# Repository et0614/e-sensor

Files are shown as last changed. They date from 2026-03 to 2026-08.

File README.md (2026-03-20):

# E-Sensor Project

This project provides a complete solution for a MIDI-based sensor device, including hardware design files, microcontroller firmware, and a Python client library.

## Directory Structure

The repository is organized as follows:

```text
.
├── firmware/                # Microcontroller Firmware (MPLAB X IDE)
│   ├── E_Sensor_Main.X/     # Main controller (USB-MIDI & System Logic)
│   └── E_Sensor_Velocity.X/ # Sub-controller (Air velocity sensor processing)
├── hardware/                # Hardware Design Materials
│   ├── pcb/                 # PCB layout and schematics
│   ├── datasheets/          # Technical specifications for key components
│   └── BOM.xlsx             # Bill of Materials
├── software/                # PC-side Applications & Libraries
│   ├── e_sensor.py          # Python client library for E-Sensor
│   └── requirements.txt     # Python dependency list
└── .gitignore               # Git ignore rules for MPLAB X and Python
```

---

## Directory Details

### 1. Firmware (`/firmware`)
Contains MPLAB X IDE projects for the onboard microcontrollers.

* **E_Sensor_Main.X**: 
    * Handles USB-MIDI communication using the TinyUSB stack.
    * Manages system-level logic and MIDI SysEx protocol.
    * Configured via MCC (MPLAB Code Configurator).
* **E_Sensor_Velocity.X**: 
    * Dedicated firmware for the air velocity sensor subunit.
    * Focuses on high-speed signal processing and data filtering.

### 2. Hardware (`/hardware`)
Includes all physical design assets.

* **pcb/**: Original CAD files for the board. A `Schematic.pdf` is provided for quick reference without needing specialized CAD software.
* **datasheets/**: A collection of PDFs for the ICs and sensors used in this design, ensuring all technical references are available offline.

### 3. Software (`/software`)
Tools for interfacing with the device from a computer.

* **e_sensor.py**: 
    * A lightweight Python class that wraps the MIDI SysEx protocol.
    * Supports real-time data polling, device ID retrieval, and coefficient calibration.
* **requirements.txt**: List of necessary Python packages (e.g., `mido`, `python-rtmidi`).

---

## Getting Started

### Firmware Development
* **IDE**: MPLAB X IDE
* **Compiler**: Microchip XC8
* **Plugin**: MCC (MPLAB Code Configurator)

### Python Environment
Install dependencies using pip:
```bash
pip install -r software/requirements.txt
```

---

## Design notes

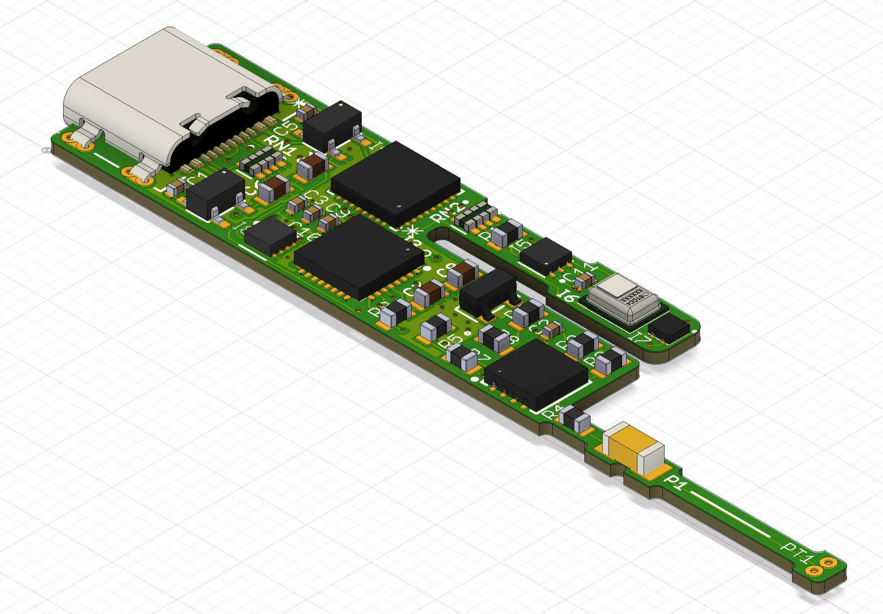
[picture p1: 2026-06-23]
hardware/pcb/3d_view.png

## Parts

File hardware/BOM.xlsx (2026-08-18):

No. | Designator | Qty | Manufacturer | Manufacturer Part Number | Spec | RoHS | Link
1 | C1, C2, C3, C5, C9, C10, C11 | 7 | Samsung Electro-Mechanics | CL05B104KO5NNNC | 0.1 uF | x | https://www.lcsc.com/product-detail/C1525.html
2 | C4, C6, C7 | 3 | Samsung Electro-Mechanics | CL10A105KB8NNNC | 1 uF | x | https://jlcpcb.com/partdetail/16531-CL10A105KB8NNNC/C15849
3 | C8 | 1 | Murata | GRM188R60J476ME15D | 47 uF | x | https://www.digikey.jp/ja/products/detail/murata-electronics/GRM188R60J476ME15D/5877410
4 | I1 | 1 | Toshiba | TCR2EF33,LM | 3.3 V | x | https://www.digikey.jp/ja/products/detail/toshiba-semiconductor-and-storage/TCR2EF33-LM-CT/4503183
5 | I2 | 1 | Toshiba | TCR3UF20A,LM(CT | 2.0 V | x | https://www.lcsc.com/product-detail/C7067134.html
6 | I3 | 1 | ATmel | AVR128DB32T-E/RXB |  | x | https://www.digikey.jp/ja/products/detail/microchip-technology/AVR128DB32T-E-RXB/12807276
7 | I4 | 1 | ATmel | AVR64DU32-I/RXB |  | x | https://www.digikey.jp/ja/products/detail/microchip-technology/AVR64DU32-I-RXB/22611635
8 | I5 | 1 | Texas Instruments | OPT3001 |  | x | https://www.digikey.jp/ja/products/detail/texas-instruments/OPT3001DNPR/5039362
9 | I6 | 1 | Sensirion | SHT40-AD1B |  | x | https://www.digikey.jp/ja/products/detail/sensirion-ag/SHT40-AD1B-R3/14322709
10 | I7 | 1 | Sensirion | STCC4-D-R3 | CO2 | x | https://www.digikey.jp/ja/products/detail/sensirion-ag/STCC4-D-R3/26769073
11 | I8 | 1 | Texas Instruments | TPS22965DSGR |  | x | https://www.lcsc.com/product-detail/C122837.html
12 | J1 | 1 | Korean Hroparts Elec | TYPE-C-31-M-14 | Type C | x | https://www.lcsc.com/product-detail/C223907.html
13 | O1 | 1 | Microchip Technology | MCP6V02-E/MD |  | x | https://www.digikey.jp/ja/products/detail/microchip-technology/MCP6V02-E-MD/1635826
14 | P1 | 1 | VISHAY | TFPT1206L1002FV |  | x | https://www.digikey.jp/ja/products/detail/vishay-dale/TFPT1206L1002FV/1427100
15 | Q1 | 1 | JSCJ | JSCJ MMBT3904(RANGE:100-300) |  | x | https://www.lcsc.com/product-detail/C20526.html
16 | R2 | 1 | TE Connectivity Passive Product | CPF0603B2R21E1 | 2.21 Ω, 0.1%, 25ppm/C | x | https://www.digikey.jp/ja/products/detail/te-connectivity-passive-product/CPF0603B2R21E1/14007137
17 | R3 | 1 | TE Connectivity Passive Product | RQ73C1J232RBTD | 232 Ω, 0.1%, 10ppm/C | x | https://www.digikey.jp/ja/products/detail/te-connectivity-passive-product/RQ73C1J232RBTD/9480531
18 | R4 | 1 | TE Connectivity Passive Product | RQ73C1J2K74BTD | 2.74 kΩ, 0.1%, 10ppm/C | x | https://www.digikey.jp/ja/products/detail/te-connectivity-passive-product/RQ73C1J2K74BTD/9480545
19 | R5, R6 | 2 | TE Connectivity Passive Product | RQ73C1J15KBTD | 15 kΩ, 0.1%, 10ppm/C | x | https://www.digikey.jp/ja/products/detail/te-connectivity-passive-product/RQ73C1J15KBTD/9480247
20 | R7, R8 | 2 | TE Connectivity Passive Product | RQ73C1J13KBTD | 13 kΩ, 0.1%, 10ppm/C | x | https://www.digikey.jp/ja/products/detail/te-connectivity-passive-product/RQ73C1J13KBTD/9480097
21 | R9 | 1 | UNI-ROYAL | 0603WAF4701T5E | 4.7 kΩ | x | https://www.lcsc.com/product-detail/C23162.html
22 | RN1, RN2 | 2 | Panasonic | EXB-28V103JX | 10 kΩ x 4 | x | https://www.digikey.jp/ja/products/detail/panasonic-electronic-components/EXB-28V103JX/256299
23 | PT1 | 1 | Yageo Nexensos | 32208551 |  | x | https://www.digikey.jp/ja/products/detail/yageo-nexensos/32208551/6677784

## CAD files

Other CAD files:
hardware/pcb/e_sensor.f3z

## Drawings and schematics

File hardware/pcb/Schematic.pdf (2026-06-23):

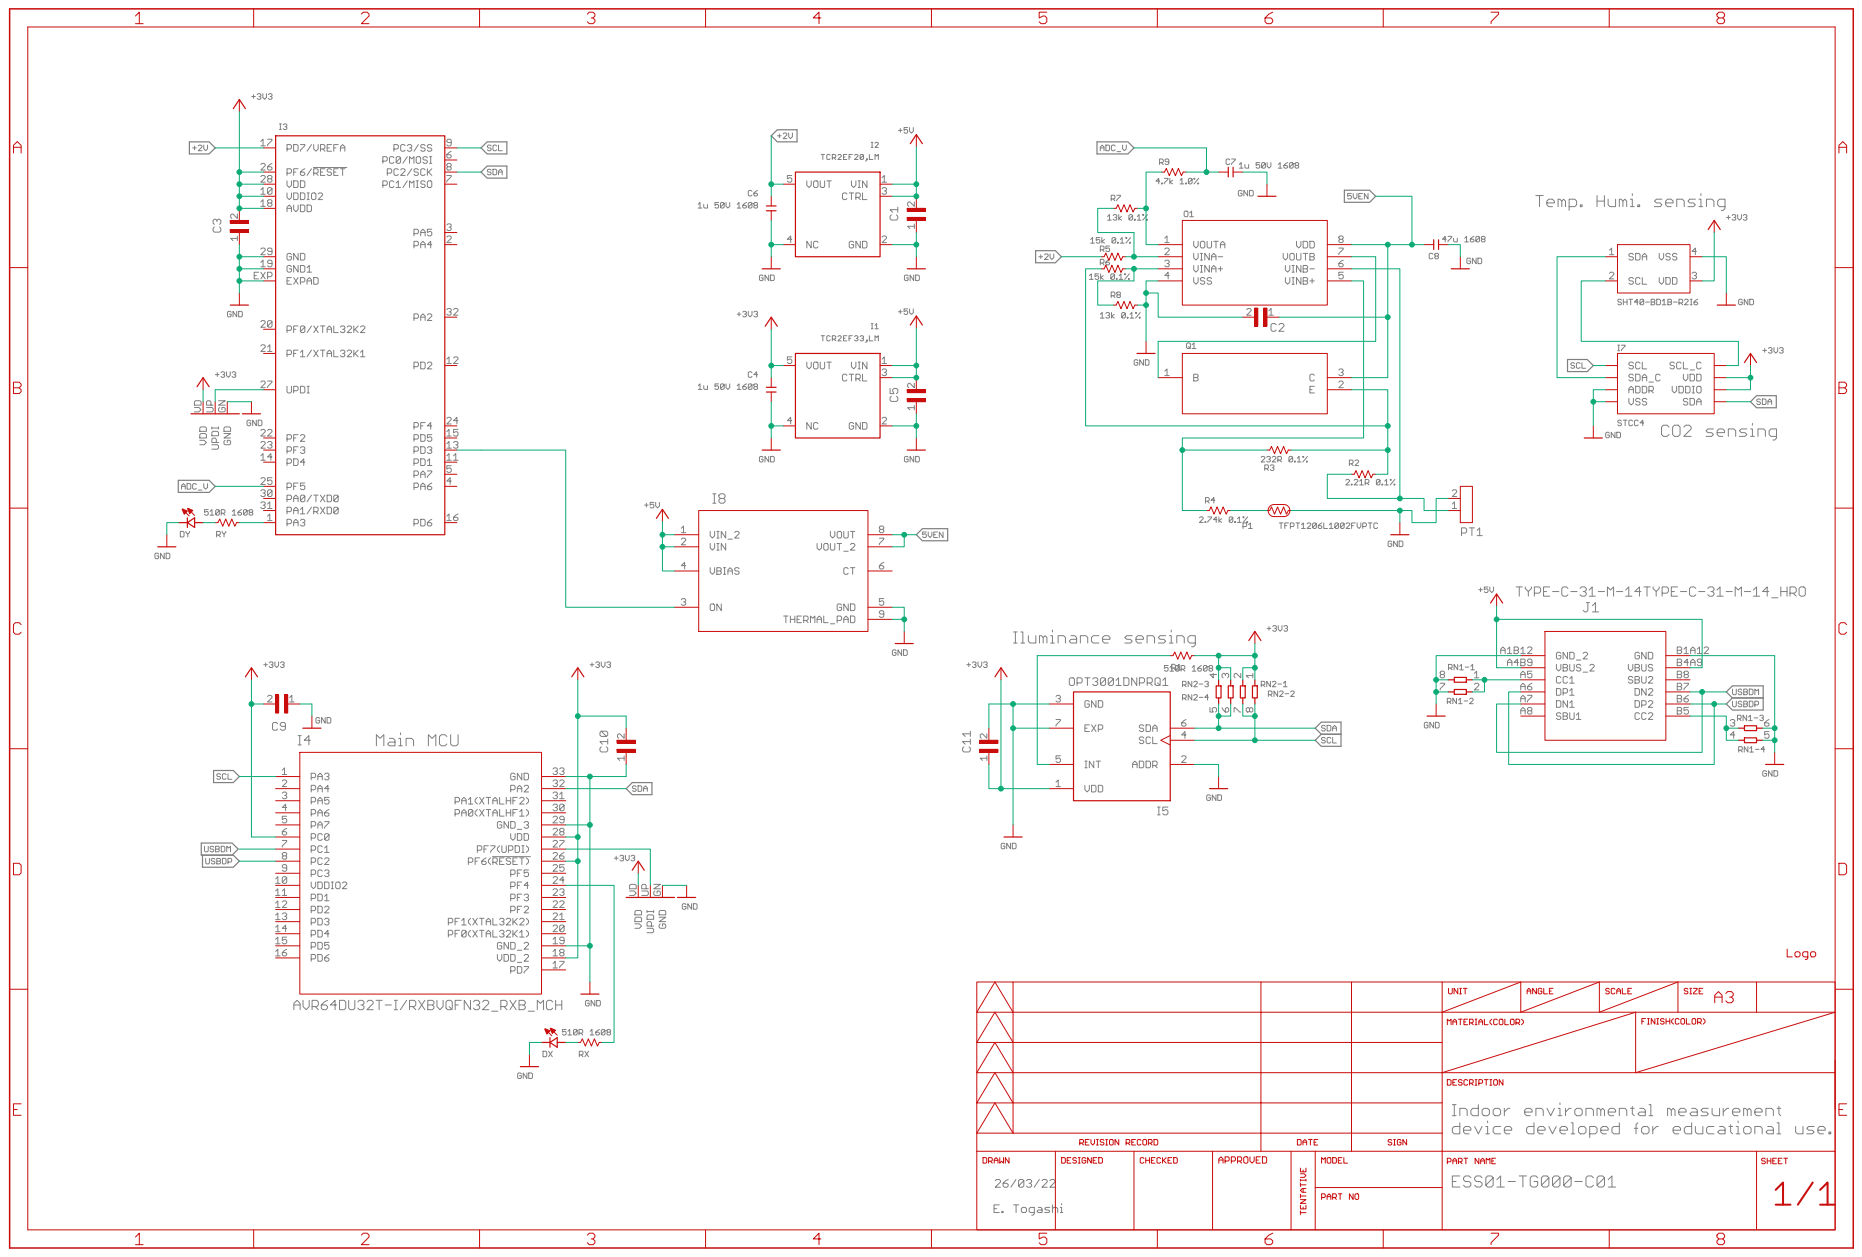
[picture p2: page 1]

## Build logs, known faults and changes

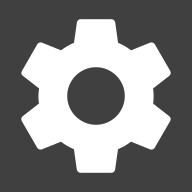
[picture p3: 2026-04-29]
software/maui/E-Sensor/Resources/Images/maintenance.png

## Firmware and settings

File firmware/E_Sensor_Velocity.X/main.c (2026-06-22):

 /*
 * AVR128DB32による風速計プログラム。
 * ブリッジ回路を応用した定温熱線式風速計の電圧を読み取り、風速に換算してI2C通信でデータを送受信する
*/

// <editor-fold defaultstate="collapsed" desc="include">

#include "mcc_generated_files/system/system.h"
#include "mcc_generated_files/adc/adc0.h"
#include "mcc_generated_files/system/pins.h"
#include "mcc_generated_files/timer/rtc.h"

#include "utility.h"
#include "i2c_slave.h"
#include "i2c_shared_data.h"
#include "smooth_filter.h"
#include "eeprom_manager.h"

#include <util/atomic.h>
#include <string.h>
#include <math.h>
#include <avr/sleep.h>
#include <avr/wdt.h>

// </editor-fold>

// <editor-fold defaultstate="collapsed" desc="定数宣言">

#define VERSION_NUMBER  (2)

#define HEATING_MSEC    (5000)  //立ち上げのための白金抵抗予熱時間[msec]

#define INTERRUPT_MSEC  (20)    //タイマの割り込み時間間隔[msec]

#define TEMP_UPDATE_MSEC (1000) //温度の更新時間間隔[msec]

#define RESET_TIME (3000)       // Resetをかけるまでの時間 [msec]

// </editor-fold>

// <editor-fold defaultstate="collapsed" desc="変数定義">

//定期更新カウンタ
volatile uint8_t tick_count = 0;

volatile uint16_t reset_timer = RESET_TIME;

//立ち上げのための白金抵抗予熱時間[msec]
uint16_t heating_timer = HEATING_MSEC;

uint16_t temp_timer = TEMP_UPDATE_MSEC;

//風速電圧平滑化フィルタ
SmoothFilter velFilter;

// </editor-fold>

// <editor-fold defaultstate="collapsed" desc="温度測定">

// 温度測定
void updateTemperature()
{
    // チャンネルを温度センサに切り替える
    ADC0_ChannelSelect(ADC0_CHANNEL_TEMPSENSE);
    
    // サンプリング時間（風速計とは異なり高インピーダンスのため）
    ADC0.SAMPCTRL = 100;
    
    // 初期遅延(INITDLY)を設定：最大の 256 CLK_ADC を待機
    ADC0.CTRLD &= 0x1F;
    
    ADC0_ConversionStart(); // 変換開始
    while(!ADC0_IsConversionDone()); // 完了待ち (BUSYフラグが落ちるのを待つ)
    adc_accumulate_t acc_val = ADC0_AccumulatedResultGet(); // 結果を取得

    //符号反転を防ぎながらキャスト
    uint32_t safe_val = (uint32_t)acc_val;
    uint32_t voltage = safe_val * 2000UL / (4096UL * 16UL); // (12bit(4096), 128 回平均, 19bitになりAVRの仕様で3bit切り捨てられるので8で割られていることに等しい)
    
    // 2.048V基準時のADCカウント数に換算
    // 12bit ADC(4096)において 2048mV = 4096カウント なので 1mV = 2カウント
    int32_t adc_equiv = (int32_t)voltage * 2;

    // 5. 特性式を適用 (公式: T[K] = (ADC - Offset) * Gain / 4096)
    int32_t gain = (int32_t)SIGROW.TEMPSENSE0;   // 16bit Gain
    int32_t offset = (int32_t)SIGROW.TEMPSENSE1; // 16bit Offset
    
    // 0.1度単位でのケルビン温度を計算
    int32_t temp_k_x100 = ((offset - adc_equiv) * gain * 100) / 4096;
    
    uint8_t vol[2];
    vol[0] = (uint8_t)(temp_k_x100 >> 8);
    vol[1] = (uint8_t)(temp_k_x100 & 0xFF);
    uint8_t volCrc = calc_crc8(vol, sizeof(vol));
    
    ATOMIC_BLOCK(ATOMIC_RESTORESTATE) {
        SharedMemory.reg.mcu_temp_high = vol[0];
        SharedMemory.reg.mcu_temp_low  = vol[1];
        SharedMemory.reg.mcu_temp_crc = volCrc;
    }
}

// </editor-fold>

// <editor-fold defaultstate="collapsed" desc="風速測定関連">

// 風速を表す電圧のAD変換処理
uint32_t adcVelocityVoltage()
{
    if(!SharedMemory.reg.enable) return 0;
    
    //チャンネルを風速計に切り替える
    ADC0_ChannelSelect(ADC0_CHANNEL_AIN21);
    
    // サンプリング時間（小さくて良い）
    ADC0.SAMPCTRL = 0;
    
    // 初期遅延(INITDLY)を設定：0
    ADC0.CTRLD |= ADC_INITDLY_DLY0_gc;
    
    ADC0_ConversionStart(); // 変換開始
    while(!ADC0_IsConversionDone()); // 完了待ち (BUSYフラグが落ちるのを待つ)
    adc_accumulate_t acc_val = ADC0_AccumulatedResultGet(); // 結果を取得
    
    //符号反転を防ぎながらキャスト
    uint32_t safe_val = (uint32_t)acc_val;
    return  safe_val * 2000UL / (4096UL * 16UL); // (12bit(4096), 128 回平均, 19bitになりAVRの仕様で3bit切り捨てられるので8で割られていることに等しい)
}

// 風速を表す電圧を平滑化して更新
void updateVelocityVoltage()
{
    uint32_t voltage = adcVelocityVoltage();
    SF_Apply(&velFilter, voltage);

    uint8_t vol[2];
    vol[0] = (uint8_t) (velFilter.out_y >> 8);
    vol[1] = (uint8_t) (velFilter.out_y & 0xFF);
    uint8_t volCrc = calc_crc8(vol, sizeof(vol));

    //安全に書き込み
    ATOMIC_BLOCK(ATOMIC_RESTORESTATE) {
        // ビッグエンディアンで保存(下位と上位を入れ替え)
        SharedMemory.reg.voltage_high = vol[0]; // Voltage High Byte
        SharedMemory.reg.voltage_low = vol[1]; // Voltage Low Byte
        SharedMemory.reg.voltage_crc = volCrc; // Voltage CRC
    }
}

// 風速を更新
void updateVelocity()
{
    //係数取得
    float coA[5];
    ATOMIC_BLOCK(ATOMIC_RESTORESTATE) {
        memcpy(coA, (void*)SharedMemory.reg.coefficientA, sizeof(coA));
    }
    for(int i=0; i<5; i++) swap_float(&coA[i]);
    float coB[5];
    ATOMIC_BLOCK(ATOMIC_RESTORESTATE) {
        memcpy(coB, (void*)SharedMemory.reg.coefficientB, sizeof(coB));
    }
    for(int i=0; i<5; i++) swap_float(&coB[i]);
    
    // --- 3レンジ用パラメータの割り当て ---
    float vol0    = coA[0]; // 無風電圧 [V]    
    // Range 1 (Low)
    float m1      = coA[1];
    float lnC1    = coA[2];    
    // Range 2 (Mid)
    float m2      = coA[3];
    float lnC2    = coA[4];    
    // Range 3 (High)
    float m3      = coB[0];
    float lnC3    = coB[1];    
    // 切替ポイント
    float v_split1 = coB[2]; // 1つ目の切替点
    float v_split2 = coB[3]; // 2つ目の切替点

    uint16_t mVolt = (SharedMemory.reg.voltage_high << 8) + (SharedMemory.reg.voltage_low);
    float evv = (0.001 * mVolt) * (0.001 * mVolt) - vol0 * vol0;
    float vel_f;
    //無風電圧以下は確定的に0m/s
    if(evv <= 0) vel_f = 0;
    else 
    {
        float lnev = log(evv);
        // まず Range 1 で計算
        vel_f = exp(lnev * m1 + lnC1);
        // 切り替え点1を超えていたらRange 2で計算
        if(v_split1 <= vel_f) 
        {
            vel_f = exp(lnev * m2 + lnC2);            
            // さらに切替点2を超えていたら Range 3 で再計算
            if(v_split2 <= vel_f) vel_f = exp(lnev * m3 + lnC3);
        }
    }
    
    // mm/sに変換して16ビット整数化
    uint16_t vel_ui = (uint16_t) (vel_f * 1000);
    uint8_t vel[2];
    vel[0] = (uint8_t)(vel_ui >> 8);
    vel[1] = (uint8_t)(vel_ui & 0xFF);
    
    //CRC計算
    uint8_t velCrc = calc_crc8(vel, sizeof(vel));
    
    //安全に書き込み
    ATOMIC_BLOCK(ATOMIC_RESTORESTATE) {
        SharedMemory.reg.velocity_high = vel[0]; // Velocity High Byte
        SharedMemory.reg.velocity_low = vel[1]; // Velocity Low Byte
        SharedMemory.reg.velocity_crc = velCrc; // Velocity CRC
    }
}

// </editor-fold>

// <editor-fold defaultstate="collapsed" desc="main">

// 20msecタイマ用コールバック関数
void msecHandler(void) 
{
    if (tick_count < 255) tick_count++;
}

bool ledDbg = true;

int main(void)
{
    SYSTEM_Initialize();
        
    // EEPROM読み込み
    EM_loadEEPROM();
    
    // I2Cアドレスを反映
    TWI0.SADDR = SharedMemory.reg.i2c_address << 1;
    
    // デフォルトの設定
    SharedMemory.reg.version = VERSION_NUMBER;
    SharedMemory.reg.enable = 0; // 起動時は風速計OFF（5V遮断）。Main からの起動指令で開始する
    SharedMemory.reg.updated = 0;
    memcpy((void*)SharedMemory.reg.id, (const void*)&SIGROW.SERNUM0, 16); // AVR製造IDをコピー
    SharedMemory.reg.id_crc = calc_crc8((uint8_t*)SharedMemory.reg.id, 16);
    uint32_t hash = fnv1a_32((void*)SharedMemory.reg.id, sizeof(SharedMemory.reg.id));
    SharedMemory.reg.id_hash[0] = (uint8_t)(hash >> 24);
    SharedMemory.reg.id_hash[1] = (uint8_t)(hash >> 16);
    SharedMemory.reg.id_hash[2] = (uint8_t)(hash >> 8);
    SharedMemory.reg.id_hash[3] = (uint8_t)(hash & 0xFF);
    SharedMemory.reg.id_hash_crc = calc_crc8((uint8_t*)SharedMemory.reg.id_hash, 4);
    
    // 風速回路の5V電源制御（SLP = PD3 → TPS22965 ON ピン, Active High）。
    // High で5Vを供給して風速回路ON、Low で5Vを遮断してOFF（自己発熱を停止）。
    // 起動直後は enable=1 のため5Vを供給して白金抵抗の予熱を開始する。
    if (SharedMemory.reg.enable) SLP_SetHigh();
    else SLP_SetLow();

    // イベントハンドラ登録
    RTC_SetOVFIsrCallback(msecHandler);
    
    // I2C通信初期化
    I2C_Slave_Init();
    
    // 風速電圧平滑化フィルタの初期化
    SF_Init(&velFilter, SharedMemory.reg.filter_n, 0); //平滑化の目安：2^6*INTERRUPT_MSEC(1.28 sec)
        
    // スリープモード設定
    set_sleep_mode(SLEEP_MODE_IDLE);
    
    // 割り込み開始
    sei();
    
    uint8_t prev_enabled = SharedMemory.reg.enable;
    while(1)
    {
        // WDT (FUSE で 4.1s) のキック。EEPROM 書き込み・I2C 通信・浮動小数点計算など
        // 比較的長い処理を含むがいずれも秒オーダ未満で完了するため、ループ先頭の
        // 1 か所で十分。SLEEP_MODE_IDLE では WDT も計時継続するが、I2C/RTC 割込で
        // 短時間で復帰してここを通る。
        wdt_reset();

        // マスタからの設定変 更リクエストを確認
        if (I2C_Config_Update_Requested)
        {
            I2C_Config_Update_Requested = false;

            // Main からのスリープ/起動指令（enable レジスタ）に応じて
            // 風速回路の5V電源（PD3 → TPS22965 ON, Active High）を切り替える
            if (prev_enabled != SharedMemory.reg.enable)
            {
                if(SharedMemory.reg.enable == 1)
                {
                    // 5V回路起動（PD3=High → TPS22965 ON）
                    SLP_SetHigh();

                    // 再給電直後は白金抵抗が冷えているため予熱時間をリセット
                    heating_timer = HEATING_MSEC;
                }
                // 5V回路停止（PD3=Low → TPS22965 OFF、自己発熱を停止）
                else SLP_SetLow();
                
                // 状態を保存
                prev_enabled = SharedMemory.reg.enable;
            }            
            
            // 現在の出力値を初期値として、新しい n 数でフィルタを再初期化
            SF_Init(&velFilter, SharedMemory.reg.filter_n, velFilter.out_y);
            
            //EEPROMを更新
            EM_updateEEPROM();
        }
        
        //係数変更リクエストを確認
        if(I2C_Coefficient_Update_Requested)
        {
            I2C_Coefficient_Update_Requested = false;
            
            //EEPROMを更新
            EM_updateEEPROM();
        }
        
        // 定期更新処理
        if(tick_count)
        {
            ATOMIC_BLOCK(ATOMIC_RESTORESTATE) { tick_count--; }
            // I2C有効時間を更新
            if(0 < I2C_KeepAlive_Ticks)
            {
                ATOMIC_BLOCK(ATOMIC_RESTORESTATE) { 
                    I2C_KeepAlive_Ticks = (I2C_KeepAlive_Ticks < INTERRUPT_MSEC) ? 0 : (I2C_KeepAlive_Ticks - INTERRUPT_MSEC);
                }
            }
                        
            //リセット処理
            /*if(RST_SW_GetValue() == 0)
            {
                reset_timer = reset_timer < INTERRUPT_MSEC ? 0 : reset_timer - INTERRUPT_MSEC;
                if(reset_timer == 0)
                {
                    // EEPROMの初期化処理
                    EM_resetEEPROM();
                    reset_timer = RESET_TIME;
                }
            }
            else reset_timer = RESET_TIME;*/
            
            //残予熱時間を更新
            heating_timer = (heating_timer < INTERRUPT_MSEC) ? 0 : (heating_timer - INTERRUPT_MSEC);
            
            // ステータスレジスタの更新
            ATOMIC_BLOCK(ATOMIC_RESTORESTATE) {
                if (heating_timer > 0) SharedMemory.reg.status |= STATUS_HEATING_MASK; // 予熱中
                else SharedMemory.reg.status &= ~STATUS_HEATING_MASK; // 予熱完了
            }
                        
            //計測準備が整っていれば
            if (SharedMemory.reg.enable == 1 && heating_timer == 0) 
            {
                // 風速電圧[mV]を更新
                updateVelocityVoltage();
                
                // 風速[mm/s]を更新
                updateVelocity();
                
                // 計測フラグ更新
                SharedMemory.reg.updated = 1;
            }
            
            // 温度更新
            temp_timer = (temp_timer < INTERRUPT_MSEC) ? 0 : (temp_timer - INTERRUPT_MSEC);
            if(temp_timer == 0)
            {
                updateTemperature();
                temp_timer = TEMP_UPDATE_MSEC;
            }
            
            //DEBUG*****
            if(SharedMemory.reg.enable == 1) R_LED_SetHigh();
            else R_LED_SetLow();
            //DEBUG*****
        }
        
        // スリープモードは常に IDLE とする。
        // 停止中(enable=0)に PWR_DOWN へ入れると RTC が停止して msecHandler が来ず、
        // メインループが回らないため wdt_reset() を呼べない。WDT(FUSE 4.1s)が有効だと
        // 約4秒でWDTリセットがかかり、再起動時に enable=1(既定)へ戻って 5V(PD3) が
        // 復活してしまう（OFF にしても数秒で給電が戻る不具合）。IDLE なら RTC 割込で
        // 20ms 毎に起床して WDT をキックし続けるため、enable=0(PD3 Low, 5V OFF) を
        // 保持できる。発熱源である 5V 回路は PD3 で遮断済みのため目的は達成される。
        // ※さらに深い省電力(PWR_DOWN)が必要なら FUSE で WDT を無効化する必要がある。
        set_sleep_mode(SLEEP_MODE_IDLE);
        sleep_mode();
    }    
}

// </editor-fold>

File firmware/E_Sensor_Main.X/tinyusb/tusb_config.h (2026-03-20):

/*
 * The MIT License (MIT)
 *
 * Copyright (c) 2019 Ha Thach (tinyusb.org)
 *
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
 */

#ifndef _TUSB_CONFIG_H_
#define _TUSB_CONFIG_H_

#ifdef __cplusplus
 extern "C" {
#endif

//--------------------------------------------------------------------+
// Board Specific Configuration
//--------------------------------------------------------------------+

// RHPort number used for device can be defined by board.mk, default to port 0
#ifndef BOARD_TUD_RHPORT
#define BOARD_TUD_RHPORT      0
#endif

// RHPort max operational speed can defined by board.mk
#ifndef BOARD_TUD_MAX_SPEED
#define BOARD_TUD_MAX_SPEED   OPT_MODE_DEFAULT_SPEED
#endif

//--------------------------------------------------------------------
// Common Configuration
//--------------------------------------------------------------------

// defined by compiler flags for flexibility
#ifndef CFG_TUSB_MCU
//#error CFG_TUSB_MCU must be defined
#define CFG_TUSB_MCU OPT_MCU_AVRDU
#endif

#ifndef CFG_TUSB_OS
#define CFG_TUSB_OS           OPT_OS_NONE
#endif

#ifndef CFG_TUSB_DEBUG
#define CFG_TUSB_DEBUG        0
#endif

// Enable Device stack
#define CFG_TUD_ENABLED       1

// Default is max speed that hardware controller could support with on-chip PHY
#define CFG_TUD_MAX_SPEED     BOARD_TUD_MAX_SPEED

/* USB DMA on some MCUs can only access a specific SRAM region with restriction on alignment.
 * Tinyusb use follows macros to declare transferring memory so that they can be put
 * into those specific section.
 * e.g
 * - CFG_TUSB_MEM SECTION : __attribute__ (( section(".usb_ram") ))
 * - CFG_TUSB_MEM_ALIGN   : __attribute__ ((aligned(4)))
 */
#ifndef CFG_TUSB_MEM_SECTION
#define CFG_TUSB_MEM_SECTION
#endif

#ifndef CFG_TUSB_MEM_ALIGN
#define CFG_TUSB_MEM_ALIGN    __attribute__ ((aligned(4)))
#endif

//--------------------------------------------------------------------
// DEVICE CONFIGURATION
//--------------------------------------------------------------------

#ifndef CFG_TUD_ENDPOINT0_SIZE
#define CFG_TUD_ENDPOINT0_SIZE   64
#endif

//------------- CLASS -------------//
#define CFG_TUD_CDC              0
#define CFG_TUD_MSC              0
#define CFG_TUD_HID              0
#define CFG_TUD_MIDI             1 //MIDI有効化
#define CFG_TUD_VENDOR           0

#define CFG_TUD_CDC_NOTIFY        1 // Enable use of notification endpoint

// CDC FIFO size of TX and RX
#define CFG_TUD_CDC_RX_BUFSIZE   (TUD_OPT_HIGH_SPEED ? 512 : 64)
#define CFG_TUD_CDC_TX_BUFSIZE   (TUD_OPT_HIGH_SPEED ? 512 : 64)

// CDC Endpoint transfer buffer size, more is faster
#define CFG_TUD_CDC_EP_BUFSIZE   (TUD_OPT_HIGH_SPEED ? 512 : 64)

// MSC Buffer size of Device Mass storage
#define CFG_TUD_MSC_EP_BUFSIZE   512
     
//------------- MIDI CLASS DRIVER CONFIGURATION -------------//
// MIDIパケットのバッファサイズを設定します
// AVR64DU32（Full Speed）の場合、通常は64バイトが標準的
#define CFG_TUD_MIDI_RX_BUFSIZE  64  // 受信バッファサイズ
#define CFG_TUD_MIDI_TX_BUFSIZE  64  // 送信バッファサイズ

// USBポート0を「デバイスモード」かつ「フルスピード」で動作させる定義
#define CFG_TUSB_RHPORT0_MODE     (OPT_MODE_DEVICE | OPT_MODE_FULL_SPEED)

#ifndef CFG_TUSB_MCU
#define CFG_TUSB_MCU OPT_MCU_AVRDU
#endif
     
#ifdef __cplusplus
 }
#endif

#endif /* _TUSB_CONFIG_H_ */

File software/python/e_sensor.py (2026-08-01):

import mido
import struct
import time
import math
from dataclasses import dataclass
from typing import Optional, List, Callable, Tuple
import datetime

@dataclass
class SensorData:
    """パース済みのセンサーデータ構造体"""
    timestamp: float
    illuminance: float  # lx
    temperature: float   # C
    humidity: float      # %
    velocity: float     # m/s (内部ではmm/sで管理されているものを変換)
    voltage: float      # V
    co2: int           # ppm
    ill_valid: bool    # Bit 0 (照度)
    env_valid: bool    # Bit 1 (温湿度・CO2)
    anemo_valid: bool  # Bit 2 (風速・電圧)
    # 風速計自己発熱の温度補正(カルマンフィルタ)が有効な場合に、補正後の
    # 空気温度推定値[℃]が入る。補正無効時や温湿度無効時は None。
    # 生の temperature は補正に関わらずそのまま保持される。
    corrected_temperature: Optional[float] = None
    # 温度補正に伴って換算し直した相対湿度[%]。補正無効時や温湿度無効時は None。
    # 生の humidity はそのまま保持される。
    corrected_humidity: Optional[float] = None


class ThermalParams:
    """風速計の自己発熱による温度センサ熱影響モデルの定数。

    資料「熱影響の補正方法」§3 の同定値。詳しい導出・手法比較・検証は
    thermal_correction.py を参照（こちらは実機組み込み用に numpy 非依存で実装）。

        CB dTB/dt = Q - K(v)(TB - Ta) ,  K(v) = A + B*v [mW/K]
        定常: TB - Ta = Q/K(v)

    K(v) は実機モデルの固定値を採用。基板まわりの強制対流は平板/バルク体的で、
    熱線(細円柱)の King 則 √v ではなく風速の一次式の方が実測に合うため線形とした。
    実使用では低風速の場面が多いため、切片 A(=無風時の伝熱係数) を無風実測値に固定。

    offset_scale は定常オフセット(Q/K)に掛ける調整係数。校正時の TB-Ta を真の
    平衡前に測ったため offset がやや過小だったので、当面 1.2 としてつじつまを
    合わせる。平衡まで取り直して offset/K を再校正したら 1.0 に戻すこと。
    (offset=Q/K のため、これは実効的に Q を 1.2 倍/ K を 1/1.2 倍するのと等価。
     校正で Q はスケール自由なので、Q・A・B を触らず1係数で表現する。)
    """

    def __init__(self, Q: float = 50.0, CB: float = 1300.0, dt: float = 1.0,
                 A: float = 11.058, B: float = 130.19, offset_scale: float = 1.2):
        self.Q = Q          # トランジスタ発熱 [mW]
        self.CB = CB        # 基板熱容量 [mJ/K]
        self.dt = dt        # 既定サンプリング周期 [s]
        self.A = A          # K(v) 切片(無風時) [mW/K] — 低風速重視で実測値に固定
        self.B = B          # K(v) 風速係数 [mW/(K·(m/s))]
        self.offset_scale = offset_scale  # 定常オフセット調整係数(再校正後は 1.0)

    def K(self, v: float) -> float:
        """伝熱係数 K(v) = A + B*v [mW/K]。"""
        return max(1e-3, self.A + self.B * max(0.0, v))

    def offset(self, v: float) -> float:
        """定常自己発熱オフセット offset_scale·Q/K(v) [K]。"""
        return self.offset_scale * self.Q / self.K(v)


def _sat_vapor_pressure(t_celsius: float) -> float:
    """飽和水蒸気圧 [hPa] (Magnus/WMO 近似, 0〜50℃で十分な精度)。"""
    return 6.112 * math.exp(17.62 * t_celsius / (243.12 + t_celsius))


def correct_relative_humidity(rh: float, t_measured: float, t_air: float) -> float:
    """自己発熱で温度が変わったぶんの相対湿度補正。

    水蒸気分圧 e は定圧では加熱しても保存される量とみなせる。センサは自分の温度
    (基板温度 t_measured) での相対湿度を読むので e = RH_meas/100·esat(t_measured)。
    真の空気温度 t_air での相対湿度は
        RH_air = e/esat(t_air)·100 = RH_meas · esat(t_measured)/esat(t_air)
    t_air < t_measured (基板加熱) なら RH は上方修正される。0〜100% にクランプ。
    """
    rh_corr = rh * _sat_vapor_pressure(t_measured) / _sat_vapor_pressure(t_air)
    return max(0.0, min(100.0, rh_corr))


class KalmanThermalCorrector:
    """2状態カルマンフィルタ(資料 §4)による空気温度の推定。

    状態 x=[TB, Ta] (基板温度, 空気温度)。基板温度 TB(センサ計測値) と風速 v
    から、自己発熱の過渡をモデルで差し引いて空気温度 Ta を推定する。
    MCU/軽量実行を想定し numpy 非依存(2x2 を手計算)。
    """

    def __init__(self, params: Optional[ThermalParams] = None,
                 meas_std: float = 0.03,     # 観測(センサ)雑音 σ [K]
                 air_std: float = 0.005,     # 空気温度の1ステップ変動 σ [K] (プロセス雑音)
                 board_std: float = 0.002,   # 基板状態のモデル雑音 σ [K]
                 init_air_std: float = 0.5,  # 起動時の空気温度の初期不確かさ σ [K]
                 gate_abs: float = 2.0):     # 外れ値ゲート: 残差の許容上限 [K]
        # air_std を小さくするほど補正後の揺れは小さくなる(平滑)が、真の空気温度
        # 変化への追従は遅くなる。室内空気はゆるやかに変化するため小さめが良い。
        # 基板の自己発熱リップル(対流/制御由来)は空気変動ではないので、小さい
        # air_std で抑制するのが正しい。
        self.p = params or ThermalParams()
        self.R = meas_std ** 2
        self.qb = board_std ** 2
        self.qa = air_std ** 2
        self.gate_abs = gate_abs
        self._init_board_var = meas_std ** 2
        self._init_air_var = init_air_std ** 2
        self.reset()

    def reset(self):
        """フィルタ状態を初期化する。"""
        self.xb: Optional[float] = None   # 基板温度状態
        self.xa: Optional[float] = None   # 空気温度状態
        # 誤差共分散 P (対称 2x2)。
        # 接続開始時は「基板温度 ≒ 周囲空気温度 (自己発熱はこれから蓄積する)」と
        # 分かっているため、空気状態の初期不確かさを小さく取る(コールドスタート前提)。
        # こうしないと開始直後にフィルタが空気温度を過剰に引き下げ(基板はまだ昇温前
        # なのに定常オフセット分を差し引こうとする)、推定値がストンと落ちてしまう。
        # 自己発熱の立ち上がりはモデル(F の動特性)が時間をかけて表現する。
        self.p00 = self._init_board_var
        self.p01 = 0.0
        self.p11 = self._init_air_var

    def update(self, z: float, v: float, dt: Optional[float] = None,
               heating: bool = True, measured: bool = True) -> Optional[float]:
        """1サンプル進めて推定空気温度[℃]を返す。

        z        : 基板温度(センサ計測値) [℃]
        v        : 風速 [m/s]
        dt       : 前回からの経過時間 [s] (None なら params.dt)
        heating  : 風速計が稼働(自己発熱)中なら True。停止中は Q=0 として扱い、
                   オフセットを与えず基板が空気温度へ冷える過程をモデル化する。
        measured : 有効な温度観測があれば True。False(欠測=温度の読み取り失敗)の
                   ときは観測を使わず予測ステップのみで状態を進める。これにより
                   欠測時も補正値が途切れず連続する(z は無視される)。
        """
        if dt is None:
            dt = self.p.dt
        if self.xb is None:
            # 初期化には有効な初回観測が必要
            if not measured:
                return None
            # 起動直後は自己発熱前 → Ta ≈ TB とみなして初期化
            self.xb = z
            self.xa = z
            return z

        K = self.p.K(v)
        E = math.exp(-K * dt / self.p.CB)
        # 自己発熱オフセット(調整係数込み)。停止中は加熱なしで 0。
        off = (self.p.offset_scale * self.p.Q / K) if heating else 0.0
        c = 1.0 - E

        # --- 予測:  x = F x + b ,  P = F P Fᵀ + Qw   (F=[[E,c],[0,1]]) ---
        xb = E * self.xb + c * self.xa + c * off
        xa = self.xa
        m00 = E * self.p00 + c * self.p01
        m01 = E * self.p01 + c * self.p11
        m11 = self.p11
        n00 = m00 * E + m01 * c + self.qb   # +Qw
        n01 = m01
        n11 = m11 + self.qa

        # --- 更新:  e=z-Hx , S=HPHᵀ+R , g=PHᵀ/S , x+=g e , P=(I-gH)P  (H=[1,0]) ---
        y = z - xb            # 残差 (H x = xb)
        # 欠測(measured=False)、または外れ値(基板温度は時定数 ≫ dt のため dt 秒で
        # 大きく跳ねない)の観測は使わず、予測のみを採用する。これで欠測・化け
        # データがあっても補正値は連続したまま保たれる。
        if (not measured) or abs(y) > self.gate_abs:
            self.xb, self.xa = xb, xa
            self.p00, self.p01, self.p11 = n00, n01, n11
            return self.xa
        S = n00 + self.R
        g0 = n00 / S
        g1 = n01 / S
        self.xb = xb + g0 * y
        self.xa = xa + g1 * y
        self.p00 = (1.0 - g0) * n00
        self.p01 = (1.0 - g0) * n01
        self.p11 = n11 - g1 * n01
        return self.xa
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

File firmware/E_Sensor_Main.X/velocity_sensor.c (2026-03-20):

#include <string.h>

#include "velocity_sensor.h"
#include "i2c_master.h"
#include "crc.h"

//アドレス
#define VEL_ADD (0x10)

typedef struct __attribute__((packed)){
    // [Read Only Area] -------------------------
    // 電圧[mV] (0-2000)
    uint8_t voltage_high;
    uint8_t voltage_low;
    uint8_t voltage_crc;
    
    // 風速[mm/s] (0-10000)
    uint8_t velocity_high;
    uint8_t velocity_low;
    uint8_t velocity_crc;
    
    // マイコン温度[10C]
    uint8_t mcu_temp_high;
    uint8_t mcu_temp_low;
    uint8_t mcu_temp_crc;
    
    //予熱中か否か
    uint8_t status;
    
    //バージョン
    uint8_t version;
    
    //製造ID
    uint8_t id[16];
    uint8_t id_crc;
    uint8_t id_hash[4];
    uint8_t id_hash_crc;
    
    // [Read/Write Area] ------------------------
    uint8_t enable;
    uint8_t filter_n;
    uint8_t updated;
    
    //電圧→風速換算用係数
    float coefficientA[5];
    uint8_t crc_coefA;
    float coefficientB[5];
    uint8_t crc_coefB;
    
    //I2Cアドレス変更用のロック
    uint8_t i2c_addr_unlock; 
    // I2Cアドレス
    uint8_t i2c_address;

} VelocitySensorData_t;

// アドレス定義の自動生成
typedef enum {
    ADDR_VOLTAGE  = offsetof(VelocitySensorData_t, voltage_high),
    ADDR_VELOCITY = offsetof(VelocitySensorData_t, velocity_high),
    ADDR_MCU_TEMP = offsetof(VelocitySensorData_t, mcu_temp_high),
    ADDR_STATUS   = offsetof(VelocitySensorData_t, status),
    ADDR_ENABLE   = offsetof(VelocitySensorData_t, enable),
    ADDR_FILTER   = offsetof(VelocitySensorData_t, filter_n),
    ADDR_COEF_A   = offsetof(VelocitySensorData_t, coefficientA),
    ADDR_COEF_B   = offsetof(VelocitySensorData_t, coefficientB),
    ADDR_I2C_ADDR = offsetof(VelocitySensorData_t, i2c_address),
} VelocitySensorAddr_t;

bool VELS_start()
{
    uint8_t tx_data[2];
    tx_data[0] = ADDR_ENABLE;
    tx_data[1] = 1;
	return I2C_Write(VEL_ADD, tx_data, 2);
}

bool VELS_stop()
{
    uint8_t tx_data[2];
    tx_data[0] = ADDR_ENABLE;
    tx_data[1] = 0;
	return I2C_Write(VEL_ADD, tx_data, 2);
}

bool VELS_readFilter(uint8_t *filter)
{
    const uint8_t cmd = ADDR_FILTER;
    uint8_t buffer[1];
    if (!I2C_WriteRead(VEL_ADD, &cmd, 1, buffer, 1)) return false;
    
    *filter = buffer[0];
    return true;
}

bool VELS_writeFilter(uint8_t filter)
{
    uint8_t tx_data[2];
    tx_data[0] = ADDR_FILTER;
    tx_data[1] = filter;
	return I2C_Write(VEL_ADD, tx_data, 2);
}

bool VELS_readCoefficients(float * coeffs, bool isA)
{
    const uint8_t addr = isA ? ADDR_COEF_A : ADDR_COEF_B;
    uint8_t buffer[21]; // 20 bytes (float[5]) + 1 byte (CRC)

    // 21バイト分を読み出す
    if (!I2C_WriteRead(VEL_ADD, &addr, 1, buffer, 21)) return false;

    // データ部分(20B)のCRCをチェック
    if (CRC_calc8(buffer, 20) != buffer[20]) return false;

    // バッファからfloat配列へ一括コピー
    memcpy(coeffs, buffer, 20);
    
    return true;
}

bool VELS_writeCoefficients(float * coeffs, bool isA)
{
    const uint8_t addr = isA ? ADDR_COEF_A : ADDR_COEF_B;
    uint8_t buffer[22]; // 1 byte (addr) + 20 bytes (data) + 1 byte (CRC)

    // 送信バッファの組み立て
    buffer[0] = addr;
    memcpy(&buffer[1], coeffs, 20);
    
    // データ部分(21バイト目)にCRCを付与
    buffer[21] = CRC_calc8(&buffer[1], 20);

    // I2Cで一括送信 [Address, Data0...Data19, CRC]
    return I2C_Write(VEL_ADD, buffer, 22);
}

bool VELS_readMeasurement(uint16_t * velocity, uint16_t * voltage)
{
    const uint8_t cmd = ADDR_VOLTAGE;
    uint8_t buffer[6]; // 電圧(H, L, CRC) + 風速(H, L, CRC) の計6バイト

    // 1. 電圧のアドレスから6バイト分を一括で読み出す
    if (!I2C_WriteRead(VEL_ADD, &cmd, 1, buffer, 6)) return false;

    // 2. 電圧データの整合性確認 (電圧レジスタは buffer[0:2])
    if (CRC_calc8(&buffer[0], 2) != buffer[2]) return false;
    *voltage = (uint16_t)((buffer[0] << 8) | buffer[1]);

    // 3. 風速データの整合性確認 (風速レジスタは buffer[3:5])
    if (CRC_calc8(&buffer[3], 2) != buffer[5]) return false;
    *velocity = (uint16_t)((buffer[3] << 8) | buffer[4]);
    
    return true;
}

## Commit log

2026-03-20 Initial commit.
    [BOM.xlsx, e_sensor.brd, e_sensor.sch]
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2026-04-19 Main FW の堅牢化 (Phase 1): WDT / I2C・EEPROM タイムアウト / SysEx 状態機械 / 32bitタイマのアトミック化
    - main.c: WDT (~4s) を有効化し、main ループで wdt_reset() を呼ぶ。
    sec_timer / co2_pfm_timer の読み書きを ATOMIC_BLOCK でアトミック化。
    初期調整完了後の連続計測開始が失敗した場合に I2C を叩き続けないよう 1sec
    バックオフを追加。
    - i2c_master.c: 完了待ちにループカウンタ式タイムアウトを追加し、タイムアウト
    時は TWI0 を再初期化してバスを強制復帰させる。
    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
2026-04-19 Main FW 仕様整合 (Phase 2): stcc4 includeの修正 / 係数検証 / CO2校正の符号 / コメント整理
    - stcc4.c: #include "Stcc4.h" を "stcc4.h" に修正（Linux/macOS での大文字小文字
    によるビルド不能バグ）。
    - stcc4.c: STCC4_initialize() がジェネラルコールの I2C 失敗を握り潰して常に
    true を返していたので、戻り値を伝搬するよう修正。
    - midi_app.c: CMD_COEF_A_DATA / CMD_COEF_B_DATA で受信した係数を
    (float*)decoded のキャストで直接渡していたのを memcpy 経由に変更し、
    strict-aliasing 違反を解消。加えて NaN / ±Inf / 非現実的な大きさの
    値を is_valid_coef_array()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
    [midi_app.c, stcc4.c]
2026-04-20 Python クライアント: CO2 初期調整コマンド対応 + 付随修正
    - CO2 初期調整系 3 コマンドのサポートを追加
    - CMD_CONDITIONING_REQ (0x17) H->D
    - CMD_CONDITIONING_START (0x18) D->H
    - CMD_CONDITIONING_DONE (0x19) D->H
    上記 3 定数、送信メソッド request_conditioning()、および
    開始〜完了までブロック待機する同期 API perform_conditioning(
    wait_timeout=30.0) を追加。poll() に 0x18 / 0x19 の分岐を
    追加し、コールバック on_conditioning_start / on_conditioning_done
    を発火するようにした。
    - poll() の CMD_CO2_CAL_RES 応答パースを符号付き '>h' に修正。
    ファーム側の補正値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
    [e_sensor.py]
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2026-04-23 Autodesk Fusionに対応 一部部品の入れ替え
    [BOM.xlsx, e_sensor.brd, e_sensor.sch]
2026-04-23 MAUI プロジェクトの階層をフラット化 (E-Sensor_vs/ を削除)
    software/maui/E-Sensor_vs/{E-Sensor.slnx, E-Sensor/} を 1 階層上げて
    software/maui/{E-Sensor.slnx, E-Sensor/} に変更。「_vs」サフィックスは
    MAUI である時点で VS 想定が自明なため冗長で、software/python/ と
    対称性を持たせる意味でもフラットなほうが自然なので整理した。
    .slnx 内のプロジェクト参照は相対パス (E-Sensor/E-Sensor.csproj) の
    ままなので、ソリューションを開き直せばビルドはそのまま通る。
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2026-04-23 MAUI: MacCatalyst の DI 登録修正 + CMD_START_MEAS 送信の一元化
    ## MacCatalyst の DI 登録
    - 以前は MauiProgram.cs に #if WINDOWS / ANDROID / IOS の分岐しか無く、
    MacCatalyst ターゲットでは IMidiService / ILoggingService が DI に
    登録されず起動時クラッシュしていた。
    - MacCatalyst は iOS と同じ CoreMIDI / UIKit / AVFoundation を持つため、
    csproj 側に条件付き Compile Include を追加して Platforms\iOS\ 配下の
    サービス実装 (IosMidiService / IosLoggingService) を MacCatalyst
    ビルドにも取り込む。
    - MauiProgram.cs の分岐を "#elif IOS || MACCATALYST" に拡張して
    両ターゲットで同じ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
2026-04-23 MAUI: csproj の重複 Compile 指定を撤回 (MacCatalyst ビルドエラー修正)
    PR #5 で導入した csproj の以下 ItemGroup は、MAUI SDK が MacCatalyst
    ビルド時に Platforms/iOS/ 配下を既定で Compile 対象にするため重複指定
    となり、NETSDK1022 エラーでビルドが通らなかった。
    <ItemGroup Condition="... == 'maccatalyst'">
    <Compile Include="Platforms\iOS\IosMidiService.cs" />
    <Compile Include="Platforms\iOS\IosLoggingService.cs" />
    </ItemGroup>
    MauiProgram.cs の #elif IOS || MACCATALYST 分岐だけで DI 登録は解決
    できるため、csproj の上記ブロックを削除。コメントも実態に合わせて更新。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
2026-04-23 MAUI: CO2 初期調整 / 工場出荷時リセット用のメンテナンスメニューを追加
    CO2 センサの「初期調整 (CMD_CONDITIONING_REQ = 0x17)」と「工場出荷時
    リセット (CMD_CO2_RESET_REQ = 0x15)」を MAUI から実行できるようにする。
    誤操作防止のため、ロギング開始ボタンとは並べず、左サイドバー右下の
    VER/ID 表示の左に小さな歯車アイコン (ImageButton) を 1 つ配置し、
    タップで ActionSheet を開いて操作を選ぶ 3 段階フロー (アイコン →
    ActionSheet → 確認ダイアログ) とした。
    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
2026-04-23 MAUI: メンテナンスメニューのフィードバック反映
    - ConfirmConditioningMsg: 初期調整中は CO2 だけでなく温度・湿度も
    読み取り不可になる旨を追記（英日両方）。
    - 工場出荷時リセット: 破壊的ではなく、校正データを消すわけではなく
    過去トレンドから自動校正し直すだけなので、二段階確認（RESET 入力
    の DisplayPromptAsync）を通常の Yes/No の DisplayAlertAsync に簡略化。
    ActionSheet 表示ラベルから「破壊的」の注記も削除。メッセージ本文も
    「元に戻せない」「RESET と入力して確認」の表現を差し替え。
    - ImageButton: 18x18 が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
2026-04-23 MAUI: メンテナンスボタンの最小サイズ制約を解除
    Resources/Styles/Styles.xaml の ImageButton グローバル Style が
    Material Design の最小タップ領域として MinimumHeightRequest=44 /
    MinimumWidthRequest=44 を強制していたため、WidthRequest=9 が効かず
    アイコンが 44dp のまま表示されていた。
    インスタンス側で MinimumWidthRequest=0 / MinimumHeightRequest=0 を
    明示し、9x9 が反映されるようにした。
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2026-04-23 Main FW: 起動直後の CMD_CONDITIONING_DONE 誤発火を修正
    co2_pfm_timer の初期値が 0 だったため、sei() 後の 1msec ISR が
    "if (0 <= co2_pfm_timer) co2_pfm_timer++;" の条件でブート直後から
    カウントを始めてしまい、起動から約 23 秒後に
    "if (23000 < co2_pfm_timer)" 分岐が成立して
    CMD_CONDITIONING_DONE を勝手に送信していた（ユーザー側 MAUI
    アプリで「CO2 初期調整が完了した」メッセージが毎回表示される
    原因）。
    初期値を -1 に変更し、休眠状態（ISR が触らない）で起動するように
    した。初期調整要求 (CMD_REQ_CONDITIONING) を受けたときだけ
    0 にセット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
    [main.c]
2026-04-23 MAUI iOS: 画面向きをポートレート(正立・上下反転)のみに制限
    - iPhone (UISupportedInterfaceOrientations): 縦向きのみだった所に
    PortraitUpsideDown を追加して上下反転時にも回転できるように。
    - iPad (UISupportedInterfaceOrientations~ipad): LandscapeLeft /
    LandscapeRight を削除して横向きをサポート対象外に。縦向き 2 つ
    (Portrait / PortraitUpsideDown) のみに統一。
    Android 側は Platforms/Android/MainActivity.cs で既に
    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
2026-04-29 MAUI: メンテナンスアイコンを ImageButton から Image+TapGestureRecognizer に変更
    iOS の MAUI ImageButton は、小サイズ + BackgroundColor=Transparent +
    Padding=0 の組合せで内部の UIButton.imageView が正しく描画されない
    既知の癖がある（タップ判定は ImageButton 枠が機能するためタップ自体
    は通る）。Android で動いていたものが iOS で「タップは反応するけれど
    歯車アイコンは見えない」状態になっていた。
    Image + TapGestureRecognizer に置換し、CanExecute は IsDeviceConnected
    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
2026-04-29 MAUI iOS: maintenance.svg のラスタライズ問題を修正
    実機 (iPhone) 起動時のログに以下の警告が出ており、画像ファイル
    そのものが iOS バンドル内で見つからない (= Resizetizer が
    ラスタライズに失敗したか、glob でアイテムとして拾えていない)
    状態だった:
    Microsoft.Maui.FileImageSourceService: Warning:
    Unable to load image file 'maintenance.svg'.
    3 つの対策をまとめて入れる:
    1. SVG の intrinsic サイズを 24x24 → 256x256 に変更
    (viewBox は 0 0 24 24 のままなので描画結果は同じ)。一部の
    Resizetizer 実装は極端に小さい SVG を扱えない・出力先に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
2026-04-29 MAUI iOS: 歯車アイコンを SVG → PNG (192x192) に置換
    PR #10 の SVG 改修と csproj BaseSize 追加でも iOS で
    "Microsoft.Maui.FileImageSourceService: Warning: Unable to load
    image file 'maintenance.svg'." の警告が継続して出ており、
    Resizetizer の SVG ラスタライズパス自体が iOS で機能して
    いないことが確認できた。
    SVG をやめて、cairosvg で事前に 192x192 RGBA の PNG として
    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
2026-04-29 MAUI iOS: UIRequiresFullScreen=true で iPad multitasking から opt out
    Apple Transporter のバリデーション (409) で以下のエラーが出ていた:
    Invalid bundle. The "Portrait,PortraitUpsideDown" orientations
    were provided ... but you need to include all of the
    "Portrait,PortraitUpsideDown,LandscapeLeft,LandscapeRight"
    orientations to support iPad multitasking.
    Apple のルール: iPad アプリで multitasking (Slide Over /
    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
2026-05-14 2026.05.14発注版
    [BOM.xlsx]
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2026-05-17 バックグラウンド中の MIDI 切断検知漏れに対する修正
    バックグラウンド中に MIDI ケーブルが抜けた場合、OS から切断コール
    バックが配信されず IsDeviceConnected が古いまま残るため、接続イン
    ジケータが緑のまま、ロギング開始/設定ボタンも有効のままになっていた。
    さらに記録中に同状況になると、最後の値が無限に蓄積され続けていた。
    - IsDeviceLive (= IsDeviceConnected && IsDataFresh) を新設し、接続
    インジケータと設定アイコンの表示状態をこれに紐付け
    - 操作系コマンドの CanExecute をデータ鮮度にも依存させ、復帰後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
2026-06-01 係数書き込みバグ修正 (v1.0.1)、MAUI 風速レンジオーバー表示追加
    - Main MCU の is_valid_coef_array が BE 受信バイトを LE float として
    誤解釈し、LSB バイト下位 7 bit が 0x71-0x7F の係数値を静かに弾いて
    いたバグを修正。検証用に byte swap した複製を作るよう変更
    - 既存出荷分 (v1.0.0) 向けに Python 側で安全値へ量子化するワーク
    アラウンドを e_sensor.py に追加 (誤差は 1e-6 相対以下)
    - Main MCU バージョンを 1.0.1 に更新
    - MAUI: 風速が保証レンジ (5.0 m/s) を超えた場合に ">5.0" 表示
    [e_sensor.py, midi_app.c]
2026-06-01 プログラマ変更、BOMのミス修正（コンデンサ容量））
    [BOM.xlsx]
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2026-06-07 MAUI: CO2 ウォームアップ表示追加、初期調整通知に注記追記
    - STCC4 データシート §1.1.4 のバイパス位相（連続計測開始から
    20 秒間 CO2 値が 390 ppm 固定で出力される仕様）を、ユーザーが
    実測値と誤解しないよう SensorCard 上に「WARM-UP」バッジ＋
    灰色表示で示すようにした
    - バイパス位相のトリガとして、デバイス接続時と CMD_CONDITIONING_DONE
    受信時の 2 か所で 20 秒のワンショットタイマを起動
    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
2026-06-07 MAUI: 初期調整中・風速予熱中バッジ追加、e-sensor.jp リンク追加
    - SensorCard を IsWarmup (bool) から BadgeText (string) に汎用化。
    空文字列で通常表示、非空でオレンジバッジ＋値の灰色化。
    DataTrigger の Value="" 比較が安定しないため、propertyChanged
    コールバックで code-behind から直接 IsVisible / TextColor を制御
    - CO2 初期調整中 (CONDITIONING_START〜DONE 間) は温湿度・CO2 の
    全 3 カードに「CONDITIONING / 初期調整中」バッジを表示
    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
2026-06-15 熱影響補正(カルマンフィルタ)と風速計On/Off機能を追加 (MAUI v1.1.0)
    風速計の自己発熱による温度・湿度センサへの熱影響を補正する機能を実装。
    Software (Python):
    - e_sensor.py: 2状態カルマンフィルタによる空気温度推定と、それに伴う相対湿度の
    補正(水蒸気分圧を保存量とする換算)を追加。風速計停止時は生値、欠測は予測のみで
    連続化、外れ値ゲートを実装。風速計 On/Off コマンド対応。
    - thermal_correction.py: 手法比較・パラメータ検証用ツールを追加。
    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
    [BOM.xlsx]
2026-06-15 風速計On/Offをハードスイッチ(PD3/TPS22965)で制御 (Main MCU v1.1.1)
    PD3(VEL_PWR)に接続した TPS22965 ロードスイッチ(ON=アクティブHigh)で風速回路への
    給電を直接 On/Off するよう変更。発熱を物理的に停止できる。
    - midi_app.c: CMD_START_VEL で VEL_PWR_SetHigh(給電ON)、CMD_STOP_VEL で
    VEL_PWR_SetLow(給電OFF=発熱停止)+計測値クリア。I2C 経由の SLP/enable 制御は
    On/Off 経路から除去(PD3 が物理的に給電制御するため冗長)。velocity_enabled に
    よる計測ループの I2C ゲートは維持(給電断時の I2C ハング回避)。
    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
    [BOM.xlsx]
2026-06-22 風速計On/Offの不具合修正とバージョン更新 (Main v1.1.2 / Velocity v2 / MAUI v1.1.1)
    - Velocity MCU: 5V回路On/OffをPD3(→TPS22965 ON, Active High)で制御。
    停止中はPWR_DOWNに入るとWDT(4.1s)でリセットしenable=1へ戻り5Vが
    復活する不具合を修正(常時IDLEとしwdt_resetを継続、enable=0を保持)。
    - Main MCU: 風速On/OffをI2C(VELS_start/stop=enableレジスタ)で送るよう修正。
    自身のPD3を下げるだけでVelocity側へ停止が伝わらずOFFで5Vが残る不具合を解消。
    - MAUI: 風速計OFF時に値を無効化(「停止中」バッジでグレー化)、ON時に予熱中
    「ウォームアップ中」バッジ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
    [BOM.xlsx]
2026-06-22 ファームウェア起動時のデフォルトを風速計OFFに変更
    - Velocity MCU: 起動時 enable=0（5V遮断・予熱なし）
    - Main MCU: 起動時に VELS_stop() を送信、velocity_enabled 既定を false に
    電源投入直後は風速回路を無給電とし、ホストからの起動指令でON+予熱を開始する。
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2026-06-23 hardware更新（風速On/Off回路）
    [BOM.xlsx, e_sensor.f3z]
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2026-07-21 MAUI: PMV表示の追加・iPad表示の修正・v1.1.2でのカルマン補正解除
    - PMV（予測温冷感申告）/PPD カードを追加。Popolo.Core の FangerModel で算出し、
    放射温度=気温と仮定した簡易計算とする。風速が結果に効くため風速計 ON 時のみ表示し、
    OFF 時は ---。歯車アイコンから着衣量(clo)/代謝量(met)をプリセット選択でき、
    Preferences に永続化する。SensorCard に SettingsCommand(歯車)を追加。
    - iPad(Tablet idiom)で OnIdiom が Desktop/Phone のみ指定のため既定値にフォールバックし、
    操作パネルとカードが同一セルに重なって接続時のグレー解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
2026-07-21 部品修正
    [BOM.xlsx]
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2026-08-01 校正GUI: 進捗バーをビジュアル化＋時間重み付き＋開始ボタンの誤操作防止
    - calibration_gui.py:
    - 各行に横棒(ttk.Progressbar)を追加し[x%]テキストを置換。
    - 開始ボタンは「新規接続直後(ready)かつ非実行」のみ有効化。done/failed/
    cancelled では無効のまま(誤って再校正しない)。抜線→再接続で再有効化。
    - verify=[0,0.05]・校正=[0.05,1.0] にバーを割当て、Phase1突入時に0へ戻る
    不具合を解消(進捗を連続させる)。
    - calibrate_coefficients.py:
    - 進捗をステップ番号でなく各ステップ(整定+計測)の所要時間で重み付け。
    - 整定待ち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
    [calibrate_coefficients.py, calibration_gui.py]
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2026-08-01 校正GUI: 複数個体の取り違えを多層防御で防止
    短時間に2台続けて接続すると、MIDIポート名(WinMMで非ユニーク・列挙順の接尾辞
    で区別)の解決がブレ、別々の風洞が同一デバイスを自分のものと誤認する不具合が
    あった。名前を安定ハンドルと見なさず、実接続で本人確認する三段防御を追加:
    - calibrate_coefficients.py / verify_device.py: expected_device_id を追加。測定/
    確認の直前、既存の get_device_id() 結果を期待値と照合し、不一致なら中止
    (calibrator は wrong_device=True、verify は戻り値2)。追加のMIDI往復は無し。
    - calibration_gui.py: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
    [calibrate_coefficients.py, calibration_gui.py, verify_device.py]
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2026-08-18 BOM更新
    [BOM.xlsx]
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2026-10-01 ビルド: MAUI Compatibility の版を MAUI 本体に揃える（Windows 版の CI ビルド失敗の修正）
    SkiaSharp.Extended.UI.Maui 3.0.0 が .NET 9 用の Microsoft.Maui.Controls.Compatibility
    9.0.82 を引き込み、新しい MAUI ワークロードの Windows ビルドで存在しない
    ファイル（WebView2Loader.dll 等）のコピーに失敗していた（MSB3030）。
    $(MauiVersion) で明示して本体と同じ版に揃える。
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
